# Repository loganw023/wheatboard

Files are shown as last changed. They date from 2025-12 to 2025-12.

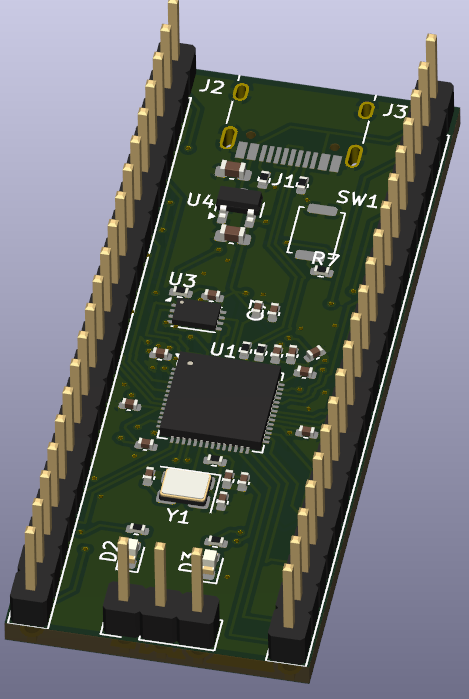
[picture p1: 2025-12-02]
Images/image-2.png

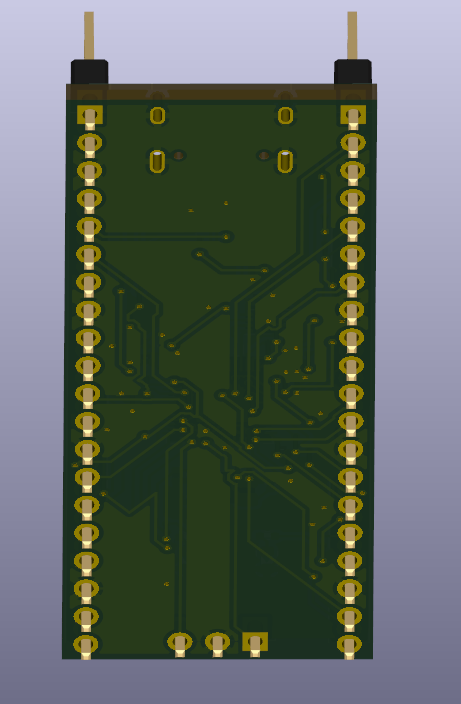
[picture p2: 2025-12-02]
Images/image-3.png

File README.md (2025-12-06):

# wheatboard
This is a custom-made devboard featuring a RP2040, I/O headers, a USB-C power supply, flash storage, crystal oscillator, and LEDs as indicators. This project was made to enhance my PCB skills, learn to use KiCad better, and qualify for Prototype, which I hope to attend. 

## Schematic 
Here is the schematic for the devboard. I tried to make it neat and organized, with labels for all major components of the devboard. Below is a screenshot: 
[i

## PCB
Here is the PCB for the devboard. The routing for the devboard took forever, since this was my first PCB project which lots of traces. I tried to organize all the components in a tight and effective manner. Below is a screenshot: 


## 3D-Model
Here is the 3D-Model for the devboard. Below is a screenshot of the top:
[
Below is a screenshot of the bottom: 


## BOM
I got the BOM from PLCPCB. One includes the parts, and the other includes the final cost. 



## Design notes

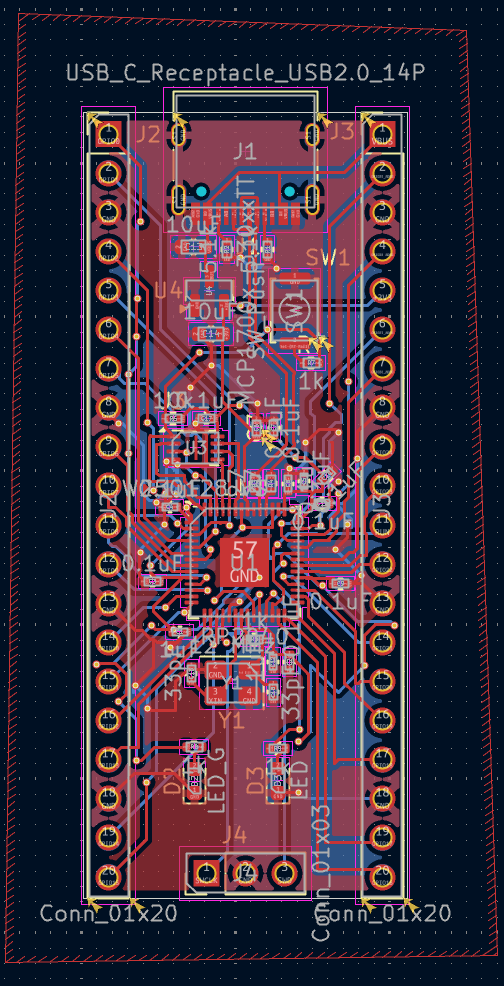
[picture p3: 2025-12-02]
Images/image.png

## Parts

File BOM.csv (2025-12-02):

Id | Designator | Footprint | Quantity | Comment | Supplier and ref
1 | R5,R8,R9,R7 | R_0402_1005Metric | 4 | 1k
2 | R4,R3 | R_0402_1005Metric | 2 | 27
3 | U4 | SOT-23 | 1 | MCP1700x-330xxTT
4 | SW1 | SW_Push_SPST_NO_Alps_SKRK | 1 | SW_Push
5 | C10,C9,C8,C6,C17,C3,C11,C2,C4,C7,C5 | C_0402_1005Metric | 11 | 0.1uF
6 | D2 | LED_0603_1608Metric | 1 | LED_G
7 | C16,C15 | C_0402_1005Metric | 2 | 33pF
8 | U1 | QFN-56-1EP_7x7mm_P0.4mm_EP3.2x3.2mm | 1 | RP2040
9 | J2,J3 | PinHeader_1x20_P2.54mm_Vertical | 2 | Conn_01x20
10 | R6 | R_0402_1005Metric | 1 | 10k
11 | C1,C12 | C_0402_1005Metric | 2 | 1uF
12 | R1,R2 | R_0402_1005Metric | 2 | 5.1k
13 | J1 | USB_C_Receptacle_HRO_TYPE-C-31-M-12 | 1 | USB_C_Receptacle_USB2.0_14P
14 | Y1 | Crystal_SMD_3225-4Pin_3.2x2.5mm | 1 | 12 MHz
15 | C13,C14 | C_0603_1608Metric | 2 | 10uF
16 | D3 | LED_0603_1608Metric | 1 | LED
17 | U3 | Winbond_USON-8-1EP_3x2mm_P0.5mm_EP0.2x1.6mm | 1 | W25Q128JVS
18 | J4 | PinHeader_1x03_P2.54mm_Vertical | 1 | Conn_01x03

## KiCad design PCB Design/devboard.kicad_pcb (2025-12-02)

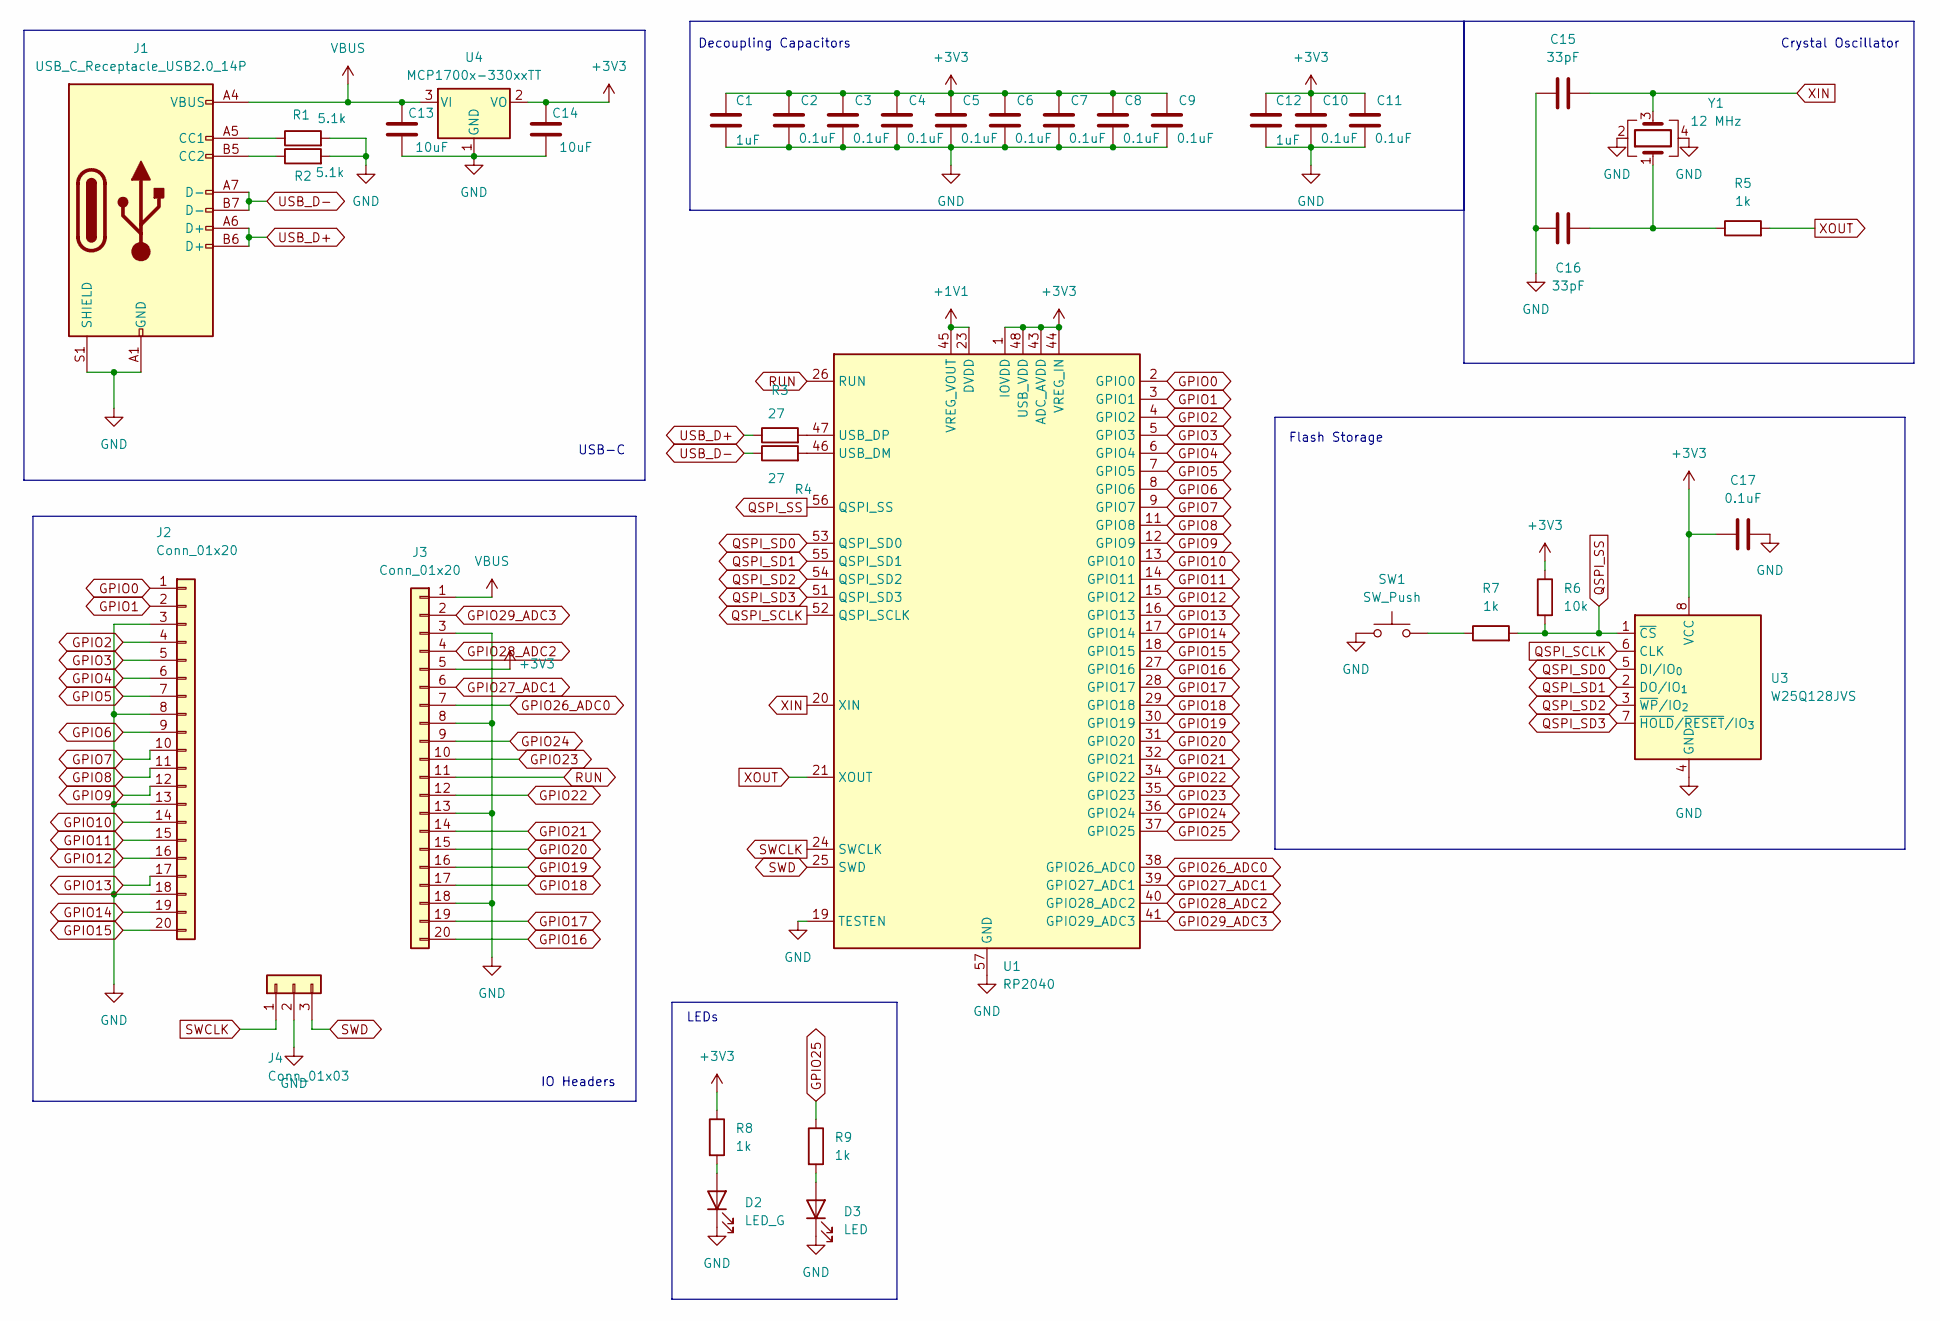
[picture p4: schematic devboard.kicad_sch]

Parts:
C1, C12: 1uF; C_0402_1005Metric
C2, C3, C4, C5, C6, C7, C8, C9, C10, C11, C17: 0.1uF; C_0402_1005Metric
C13, C14: 10uF; C_0603_1608Metric
C15, C16: 33pF; C_0402_1005Metric
D2: LED_G; LED_0603_1608Metric
D3: LED; LED_0603_1608Metric
J1: USB_C_Receptacle_USB2.0_14P; USB_C_Receptacle_HRO_TYPE-C-31-M-12
J2, J3: Conn_01x20; PinHeader_1x20_P2.54mm_Vertical
J4: Conn_01x03; PinHeader_1x03_P2.54mm_Vertical
R1, R2: 5.1k; R_0402_1005Metric
R3, R4: 27; R_0402_1005Metric
R5, R7, R8, R9: 1k; R_0402_1005Metric
R6: 10k; R_0402_1005Metric
SW1: SW_Push; SW_Push_SPST_NO_Alps_SKRK
U1: RP2040; QFN-56-1EP_7x7mm_P0.4mm_EP3.2x3.2mm
U3: W25Q128JVS; Winbond_USON-8-1EP_3x2mm_P0.5mm_EP0.2x1.6mm
U4: MCP1700x-330xxTT; SOT-23
Y1: 12 MHz; Crystal_SMD_3225-4Pin_3.2x2.5mm

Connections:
+1V1: U1.23 (DVDD), U1.45 (VREG_VOUT), U1.50 (DVDD)
+3V3: C1.1, C2.1, C3.1, C4.1, C5.1, C6.1, C7.1, C8.1, C9.1, C10.1, C11.1, C12.1, C14.1, C17.1, J3.5, R6.1, R8.1, U1.1 (IOVDD), U1.10 (IOVDD), U1.22 (IOVDD), U1.33 (IOVDD), U1.42 (IOVDD), U1.43 (ADC_AVDD), U1.44 (VREG_IN), U1.48 (USB_VDD), U1.49 (IOVDD), U3.8 (VCC), U4.2 (VO)
GND: C1.2, C2.2, C3.2, C4.2, C5.2, C6.2, C7.2, C8.2, C9.2, C10.2, C11.2, C12.2, C13.2, C14.2, C15.1, C16.1, C17.2, D2.1 (K), D3.1 (K), J1.A1 (GND), J1.A12 (GND), J1.B1 (GND), J1.B12 (GND), J1.S1 (SHIELD), J2.3, J2.8, J2.13, J2.18, J3.3, J3.8, J3.13, J3.18, J4.2, R1.2, R2.2, SW1.1, U1.19 (TESTEN), U1.57 (GND), U3.4 (GND), U4.1 (GND), Y1.2, Y1.4
GPIO0: J2.1, U1.2 (GPIO0)
GPIO1: J2.2, U1.3 (GPIO1)
GPIO2: J2.4, U1.4 (GPIO2)
GPIO3: J2.5, U1.5 (GPIO3)
GPIO4: J2.6, U1.6 (GPIO4)
GPIO5: J2.7, U1.7 (GPIO5)
GPIO6: J2.9, U1.8 (GPIO6)
GPIO7: J2.10, U1.9 (GPIO7)
GPIO8: J2.11, U1.11 (GPIO8)
GPIO9: J2.12, U1.12 (GPIO9)
GPIO10: J2.14, U1.13 (GPIO10)
GPIO11: J2.15, U1.14 (GPIO11)
GPIO12: J2.16, U1.15 (GPIO12)
GPIO13: J2.17, U1.16 (GPIO13)
GPIO14: J2.19, U1.17 (GPIO14)
GPIO15: J2.20, U1.18 (GPIO15)
GPIO16: J3.20, U1.27 (GPIO16)
GPIO17: J3.19, U1.28 (GPIO17)
GPIO18: J3.17, U1.29 (GPIO18)
GPIO19: J3.16, U1.30 (GPIO19)
GPIO20: J3.15, U1.31 (GPIO20)
GPIO21: J3.14, U1.32 (GPIO21)
GPIO22: J3.12, U1.34 (GPIO22)
GPIO23: J3.10, U1.35 (GPIO23)
GPIO24: J3.9, U1.36 (GPIO24)
GPIO25: R9.1, U1.37 (GPIO25)
GPIO26_ADC0: J3.7, U1.38 (GPIO26_ADC0)
GPIO27_ADC1: J3.6, U1.39 (GPIO27_ADC1)
GPIO28_ADC2: J3.4, U1.40 (GPIO28_ADC2)
GPIO29_ADC3: J3.2, U1.41 (GPIO29_ADC3)
unnamed: C16.2, R5.1, Y1.1
unnamed: D2.2 (A), R8.2
unnamed: D3.2 (A), R9.2
unnamed: J1.A5 (CC1), R1.1
unnamed: J1.B5 (CC2), R2.1
unnamed: R7.1, SW1.2
unnamed: R4.2, U1.46 (USB_DM)
unnamed: R3.2, U1.47 (USB_DP)
QSPI_SCLK: U1.52 (QSPI_SCLK), U3.6 (CLK)
QSPI_SD0: U1.53 (QSPI_SD0), U3.5 (DI/IO_{0})
QSPI_SD1: U1.55 (QSPI_SD1), U3.2 (DO/IO_{1})
QSPI_SD2: U1.54 (QSPI_SD2), U3.3 (~WP/IO_{2})
QSPI_SD3: U1.51 (QSPI_SD3), U3.7 (~HOLD/~RESET/IO_{3})
QSPI_SS: R6.2, R7.2, U1.56 (QSPI_SS), U3.1 (~CS)
RUN: J3.11, U1.26 (RUN)
SWCLK: J4.1, U1.24 (SWCLK)
SWD: J4.3, U1.25 (SWD)
USB_D+: J1.A6 (D+), J1.B6 (D+), R3.1
USB_D-: J1.A7 (D-), J1.B7 (D-), R4.1
VBUS: C13.1, J1.A4 (VBUS), J1.A9 (VBUS), J1.B4 (VBUS), J1.B9 (VBUS), J3.1, U4.3 (VI)
XIN: C15.2, U1.20 (XIN), Y1.3
XOUT: R5.2, U1.21 (XOUT)

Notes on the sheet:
Flash Storage
USB-C
Decoupling Capacitors
Crystal Oscillator
LEDs
IO Headers

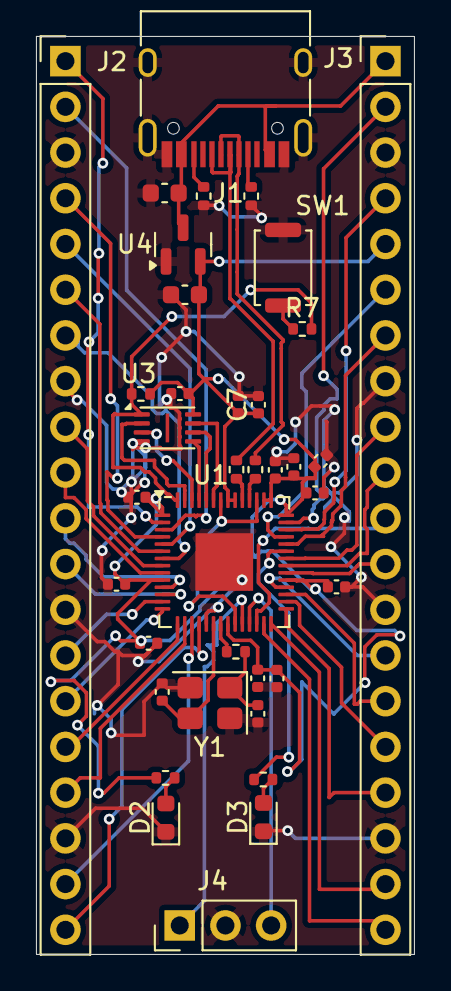
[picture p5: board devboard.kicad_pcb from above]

Board: 2 copper layers, 21.0 x 51.0 mm, 37 parts (0 on the bottom side), 55 nets.

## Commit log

2025-12-02 Added all files for project
    [BOM.csv, devboard.kicad_pcb, devboard.kicad_sch]
2025-12-02 Fixed BOM issue.
